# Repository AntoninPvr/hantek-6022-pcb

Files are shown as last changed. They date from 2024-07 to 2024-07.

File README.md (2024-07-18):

# Hantek 6022BE AC mod

Simple pcb to add AC coupling to the Hantek 6022BE oscilloscope. Based on the widespread mod available here: https://github.com/OpenHantek/OpenHantek6022/blob/main/docs/HANTEK6022_AC_Modification.pdf

Compatible with the [OpenHantek6022 project](https://github.com/OpenHantek/OpenHantek6022)

## Circuit

When `AC_A` is high `C1` is short so the signal is DC coupled. When `AC_A` is low `C1` is open so the signal is AC coupled.

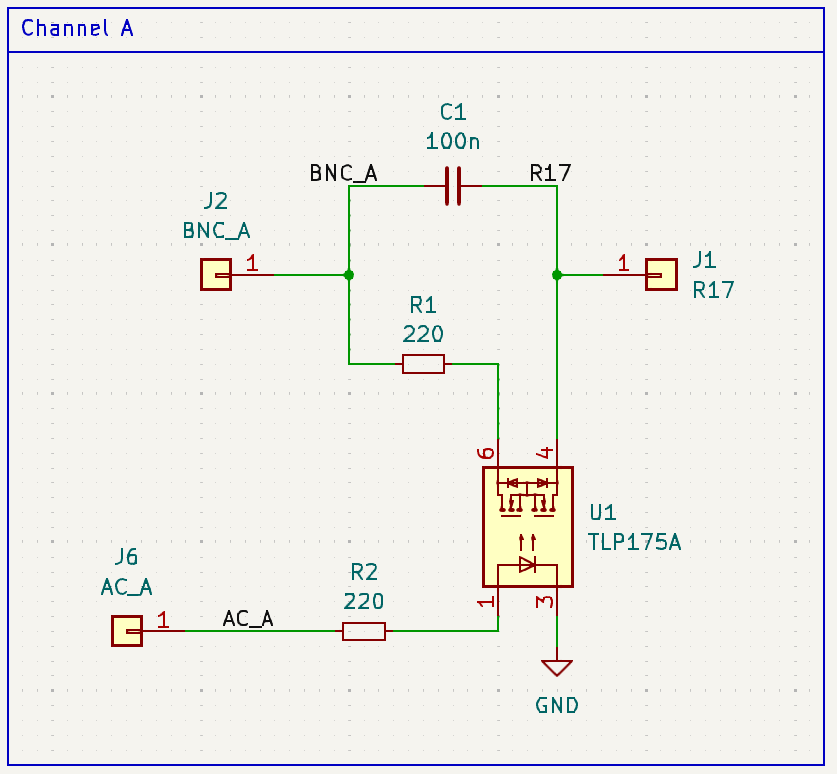
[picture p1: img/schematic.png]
schematic


## PCB

Back layer can be avoided especially in case of pcb milling.

<p float="left">
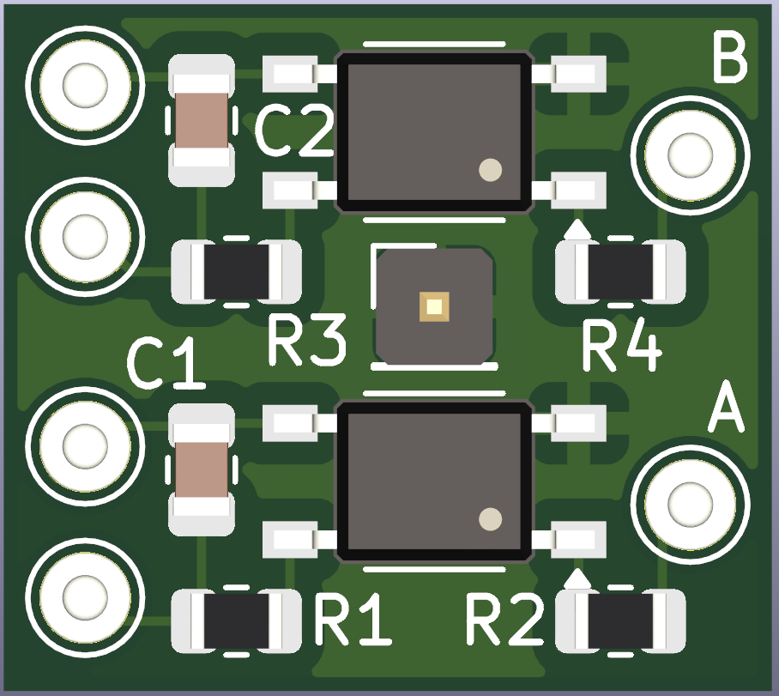
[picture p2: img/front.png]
  
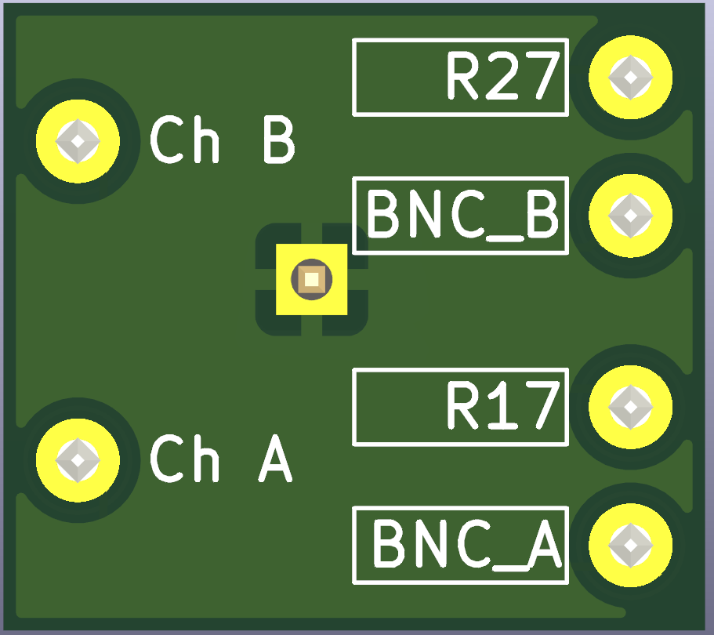
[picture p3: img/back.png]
  
</p>

## BOM
Reference | Value | Datasheet | Footprint | Qty
--- | --- | --- | --- | ---
C1,C2 | 100n | ~ | Capacitor_SMD:C_0805_2012Metric | 2
R1,R2,R3,R4 | 220 | ~ | Resistor_SMD:R_0805_2012Metric | 4
U1,U2 | TLP175A | [Datasheet](https://toshiba.semicon-storage.com/info/docget.jsp?did=13665&prodName=TLP175A) | Package_SO:MFSOP6-4_4.4x3.6mm_P1.27mm | 2

## Mounting

The pcb can be mounted on an unpopulated shield hole

<p float="left">
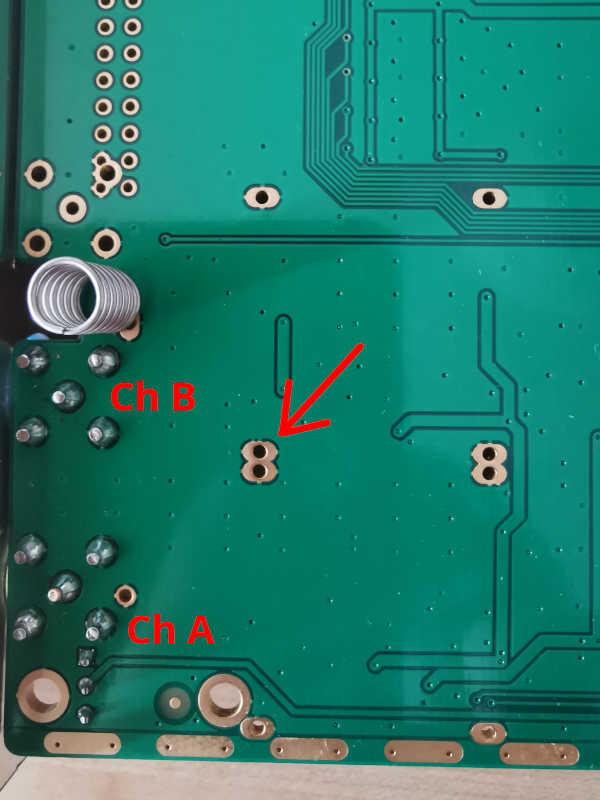
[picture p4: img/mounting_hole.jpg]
  
</p>

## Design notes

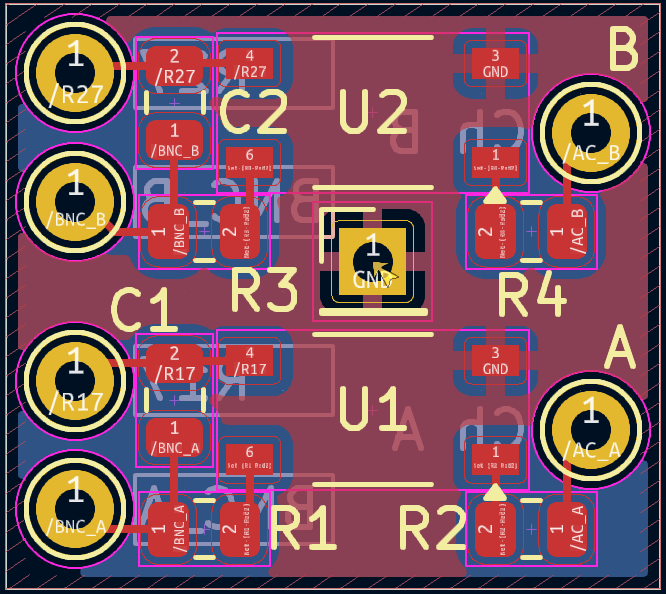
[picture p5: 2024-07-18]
img/pcb_layer.png

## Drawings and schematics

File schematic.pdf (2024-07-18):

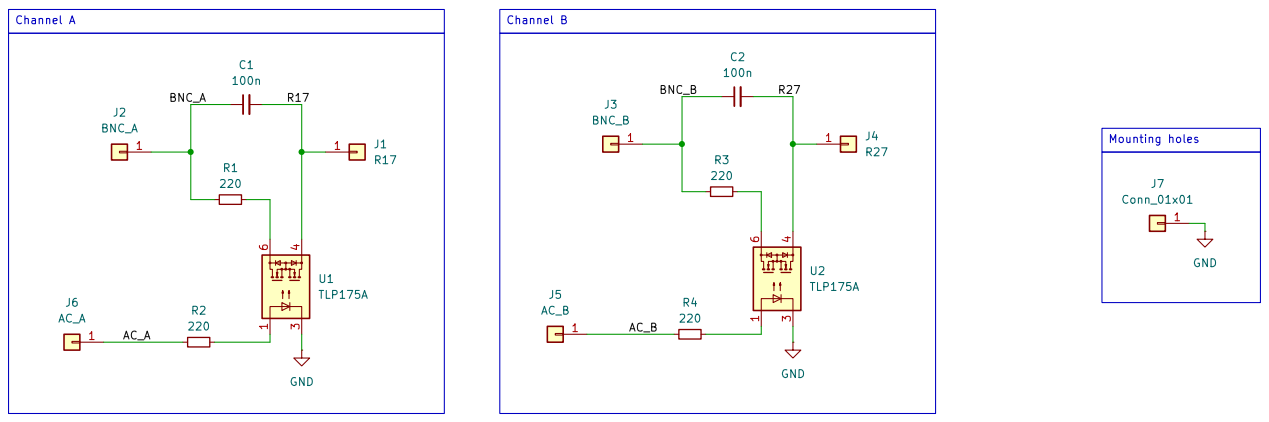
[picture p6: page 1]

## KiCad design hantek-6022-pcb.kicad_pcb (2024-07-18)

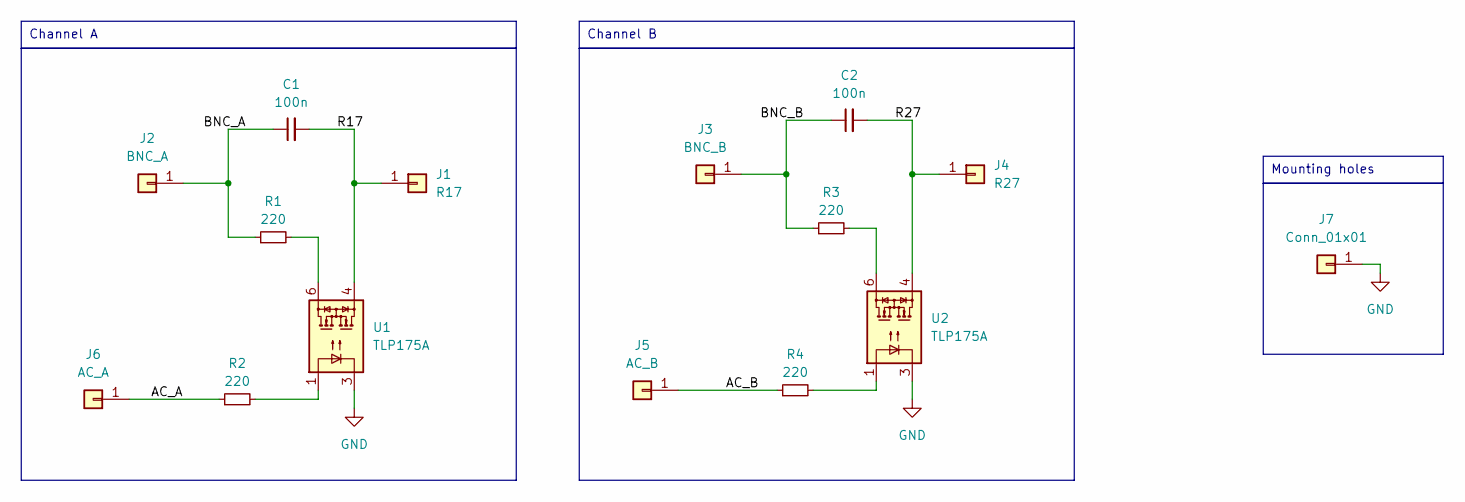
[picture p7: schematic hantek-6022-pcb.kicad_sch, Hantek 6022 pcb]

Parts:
C1, C2: 100n; C_0805_2012Metric
J1: R17; Pin_D1.0mm_L10.0mm
J2: BNC_A; Pin_D1.0mm_L10.0mm
J3: BNC_B; Pin_D1.0mm_L10.0mm
J4: R27; Pin_D1.0mm_L10.0mm
J5: AC_B; Pin_D1.0mm_L10.0mm
J6: AC_A; Pin_D1.0mm_L10.0mm
J7: Conn_01x01; PinHeader_1x01_P2.54mm_Vertical
R1, R2, R3, R4: 220; R_0805_2012Metric
U1, U2: TLP175A; MFSOP6-4_4.4x3.6mm_P1.27mm

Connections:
/AC_A: J6.1, R2.1
/AC_B: J5.1, R4.1
/BNC_A: C1.1, J2.1, R1.1
/BNC_B: C2.1, J3.1, R3.1
/R17: C1.2, J1.1, U1.4
/R27: C2.2, J4.1, U2.4
GND: J7.1, U1.3, U2.3
unnamed: R1.2, U1.6
unnamed: R2.2, U1.1
unnamed: R3.2, U2.6
unnamed: R4.2, U2.1

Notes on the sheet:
Mounting holes
Channel B
Channel A

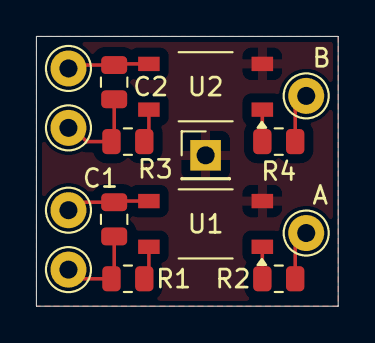
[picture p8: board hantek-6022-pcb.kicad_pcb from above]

Board: 2 copper layers, 16.8 x 15.0 mm, 15 parts (0 on the bottom side), 11 nets.
